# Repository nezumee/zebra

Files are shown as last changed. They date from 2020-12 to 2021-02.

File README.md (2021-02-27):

# Zebra
Zebra, adjustable column stagger keyboard

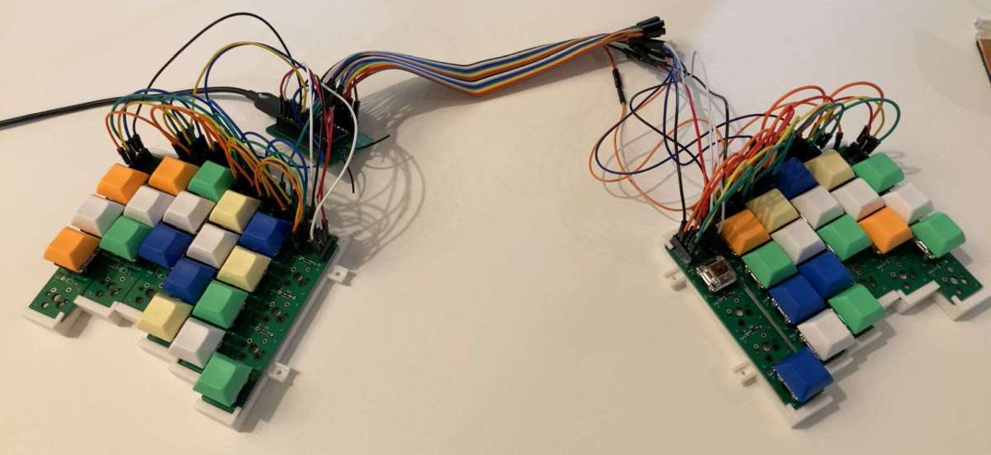
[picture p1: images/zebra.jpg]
zebra


# Overview
Zebra is a column staggered keyboard with independent PCBs for every column, allowing them to be put together in different positions or combinations without remaking any components or resoldering.

# Parts
For pictured configuration:
- Zebra head PCB x1 (see [KiCad](/PCB/Zebra) and [gerbers](/PCB/Gerber))
- Zebra stripe PCB x12. Up to 14 are supported, adjust other part counts accordingly if using more or less
- ProMicro, Elite C or equivalent x1
- ProMicro socket x1 (optional, I used https://www.digikey.com/en/products/detail/mill-max-manufacturing-corp/315-43-164-41-003000/1212143)
- 1N4148 diodes in through-hole package x48 (for example https://www.digikey.com/en/products/detail/1N4148TR/1N4148FSCT-ND/9356376?itemSeq=341430044)
- Kailh hotswap sockets x48 (optional)
- Single-line jumper wire headers x122 pins (remember every cut of header stripe means losing a pin. I bought 4x https://www.digikey.com/en/products/detail/chip-quik-inc/HDR100IMP40F-G-V-TH/5978200 and barely had any left. Get extras!)
- M/M jumper wires x65, at least 18 of them longer than 5 inches
- M/F jumper wire extender with at least 11 pins x1 (optional, to place the keyboard halves wider)
- Cherry MX switches and 1U keycaps of your choice x48
- Some way of holding the stripe PCBs in place: cardboard and sticky tape, or 3d printed enclosure, or anything else you come up with
- M2x5 screws and M2 nuts x20 (if using the 3d printed enclosure)
	
# Steps
## Solder the head PCB
1. Solder the ProMicro socket. Make sure to do it on the right side of the PCB depending on the way the pins on your ProMicro are oriented (Pin 1 is square on the PCB). My ProMicro has pins soldered so it's mounted upside down, with the MCU facing downwards
2. Solder the jumper headers on the same side
	
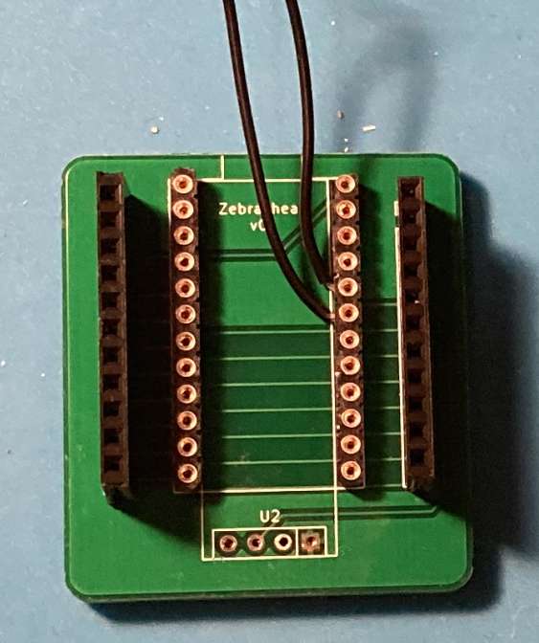
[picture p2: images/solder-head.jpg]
solder-head
	
	
	(ignore the wires in the picture)
	
## Solder the stripes
Solder the diodes, switch sockets and jumper headers
	
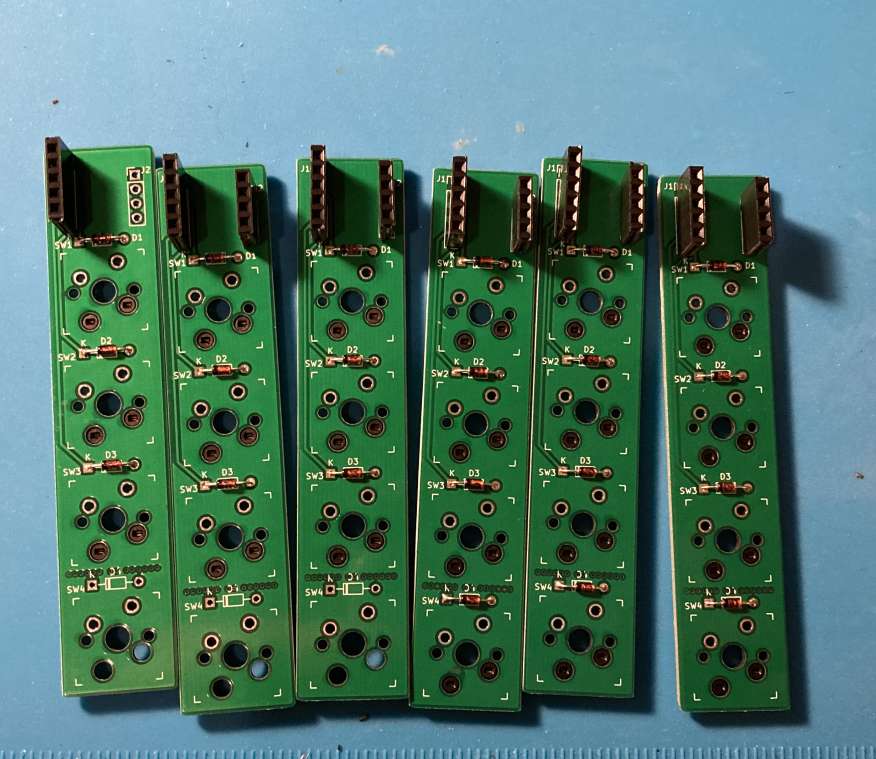
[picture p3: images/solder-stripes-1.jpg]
solder-stripes-1


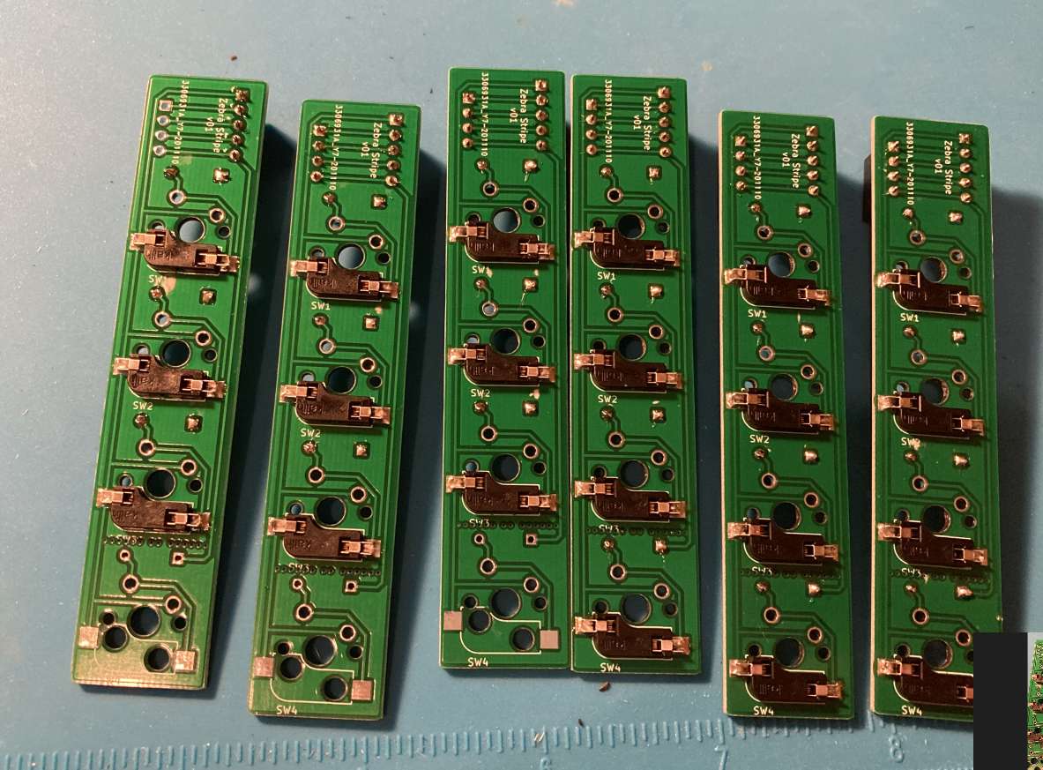
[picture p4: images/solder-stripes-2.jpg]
solder-stripes-1

	
You can skip soldering the diodes and sockets if you're not planning to use some switches (lower left).
	
## Connect the boards
Here's how the wires must be connected:
- Head

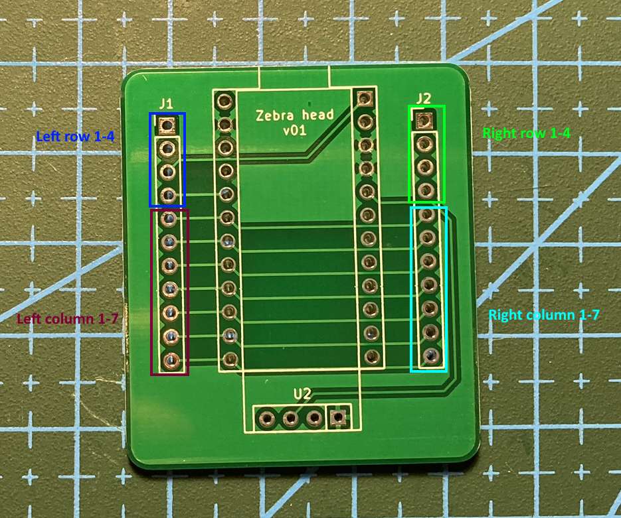
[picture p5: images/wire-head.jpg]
wire-head
	

	Note that the row wires are different between the left and right sides, don't connect them to each other!

- Stripes

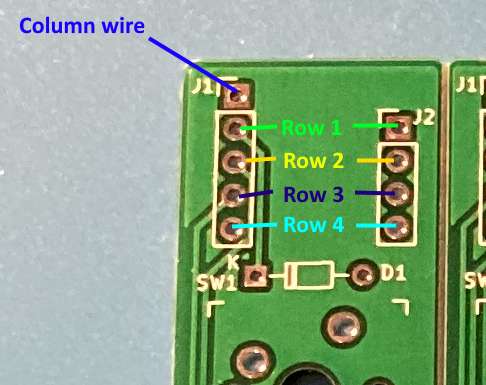
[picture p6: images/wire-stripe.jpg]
wire-stripe
	

- Overview of connections:

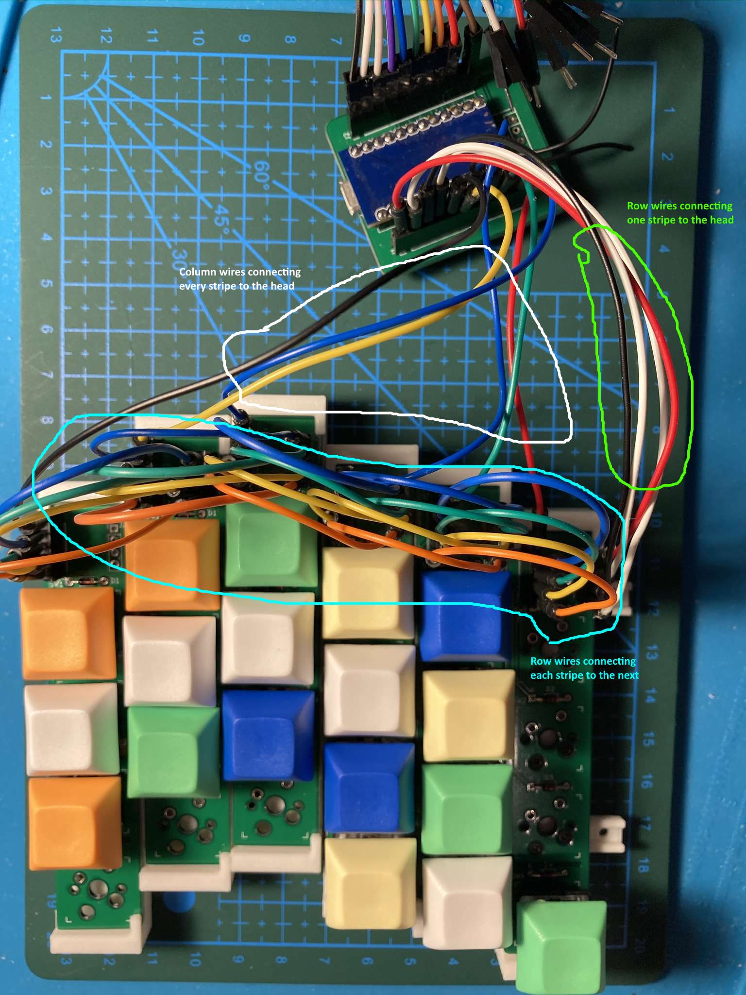
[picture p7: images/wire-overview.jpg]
wire-overview
	
	
- When connecting row wires between stripes, use the headers that are further apart so that the wires don't need to bend as much when the columns are arranged next to each other:

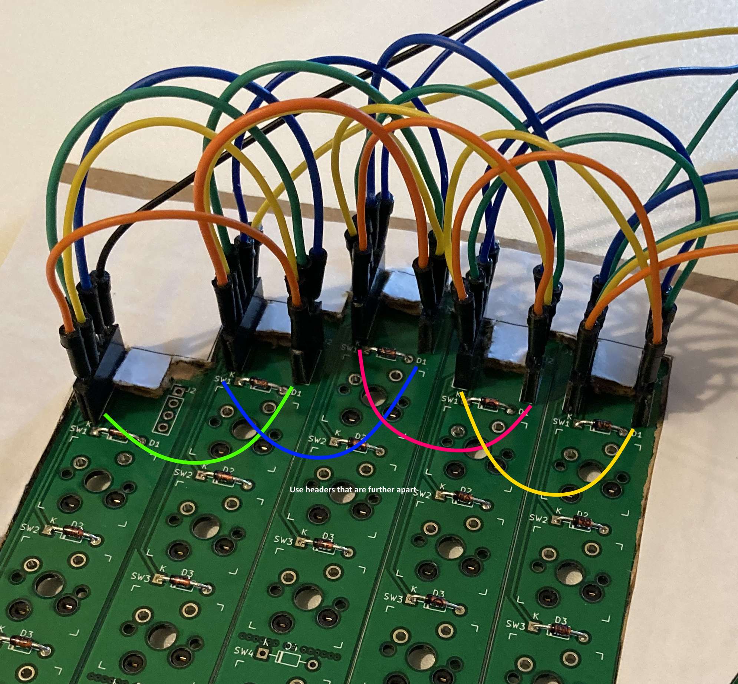
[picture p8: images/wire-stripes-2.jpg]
wire-stripes-2
	
	
## Arrange the boards
Now the difficult part - putting the stripes in place.

- Option 1: cut the shape out of cardboard that you want to place the stripes in, put some sticky tape at the back (glue side up), and stick the column boards to it:
	
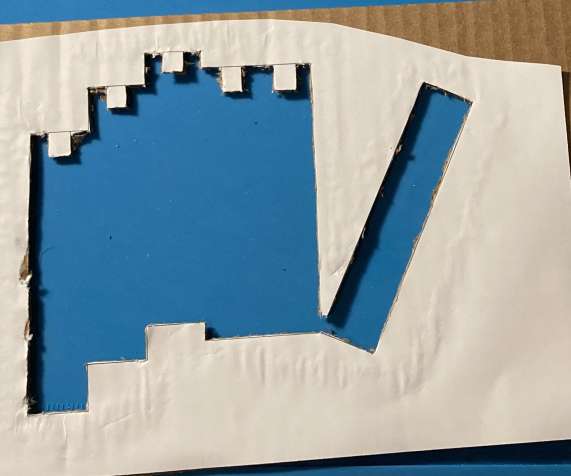
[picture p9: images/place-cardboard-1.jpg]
place-cardboard-1
	
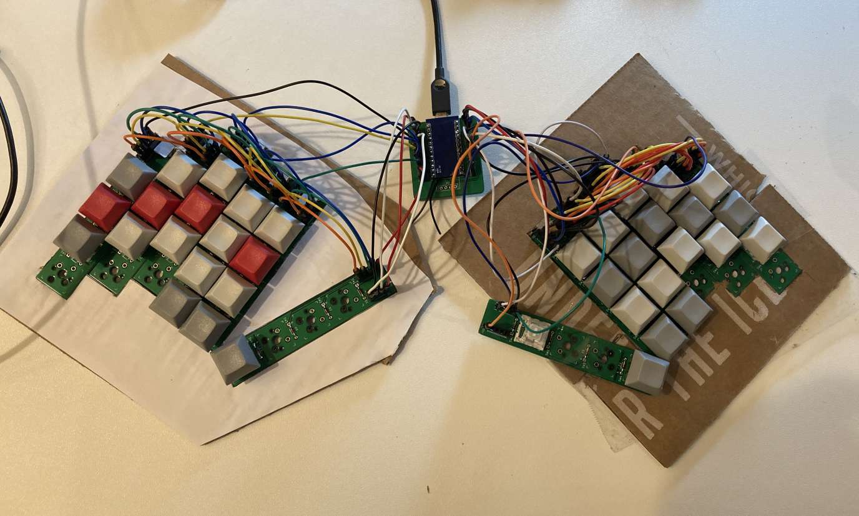
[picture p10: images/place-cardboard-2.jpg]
place-cardboard-2
	
	
	A template is available in [cardboard.svg](/Case/Cardboard.svg) file.
	
- Option 2: 3d print [stripe holders](/Case/3d-printed.stl), screw them together and insert the stripe PCBs:
	
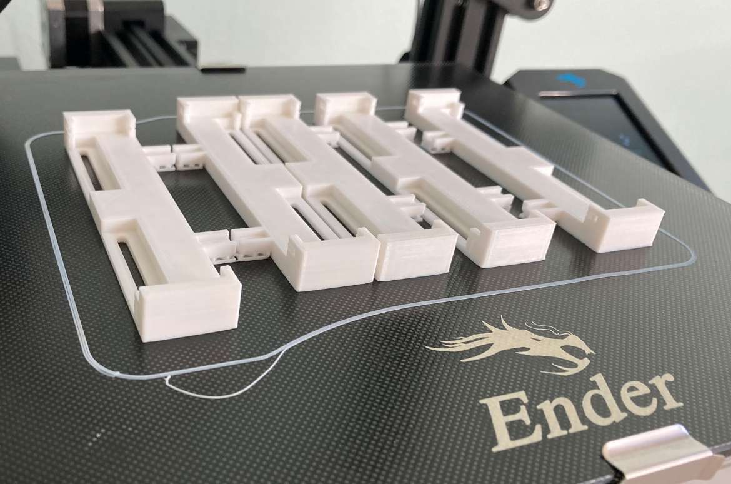
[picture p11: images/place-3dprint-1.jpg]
place-3dprint-1
	
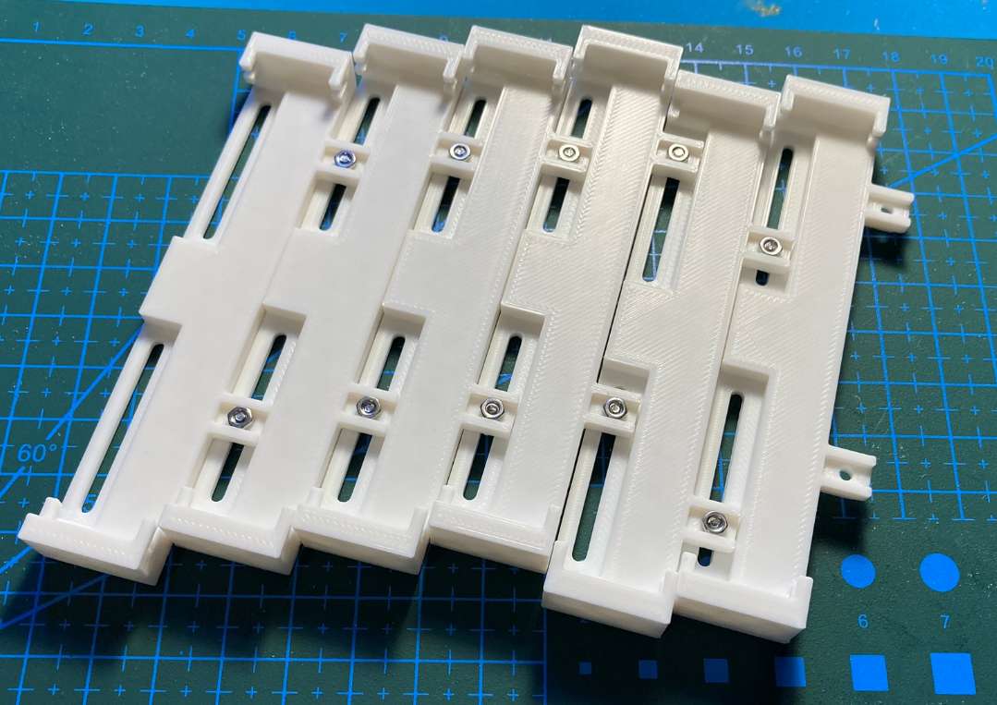
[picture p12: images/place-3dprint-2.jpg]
place-3dprint-2
	
	
	Note that a stripe allows changing stagger between 10mm in one direction and 20mm in another. Mirror half the stripes to flip which way gets more stagger on different sides of the keyboard.
	
	A basic ruler is built into the bottom of each stripe to measure the column stagger:
	
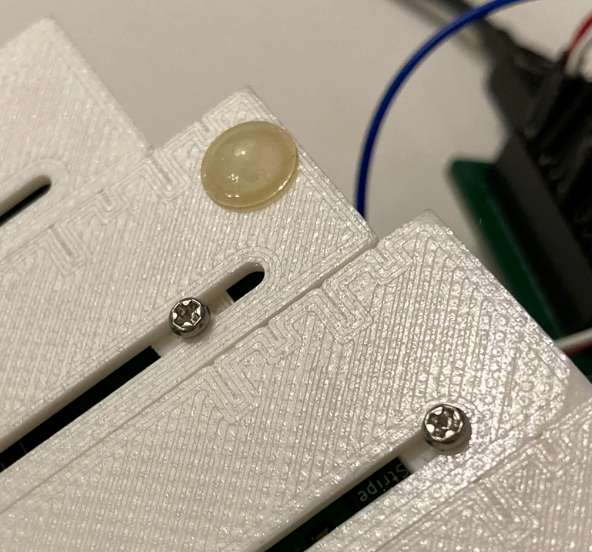
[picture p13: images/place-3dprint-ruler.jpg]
place-3dprint-ruler
	

# Firmware
Zebra is running QMK, see the source code under the QMK folder. Copy the [zebra](/QMK/zebra) folder under the keyboards folder in your QMK environment to compile. You can use JSON layout files made for Corne (LAYOUT_split_3x6_3) to build your layout in QMK configurator.

# Have fun
Try some popular or crazy configurations and see what you like!

Here's some examples:

- Let's split: no stagger

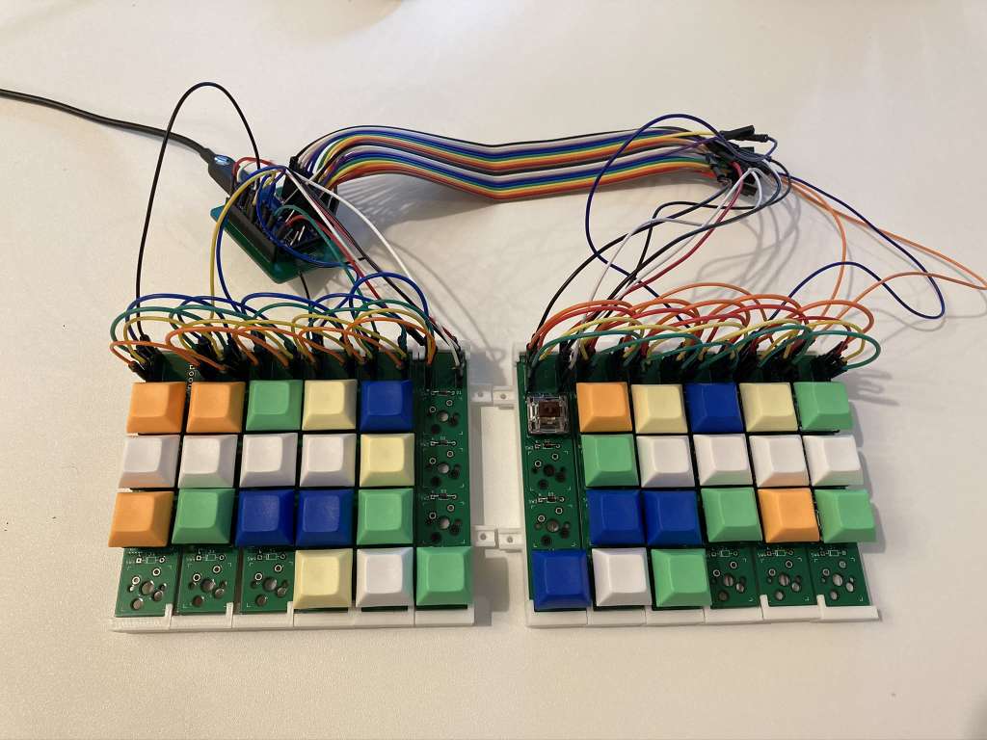
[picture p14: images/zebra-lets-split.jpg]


- Corne: index finger +2.4mm/middle +2.4mm/ring -2.4mm/pinky -4.8mm

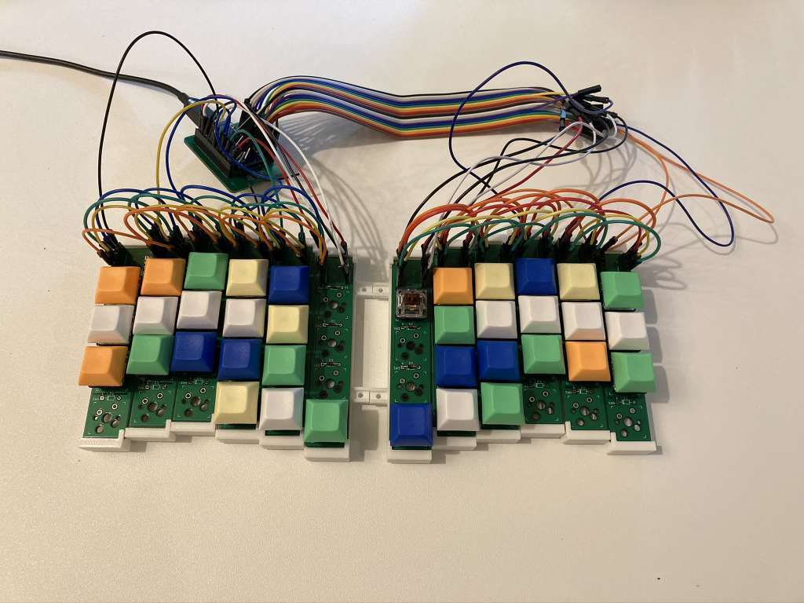
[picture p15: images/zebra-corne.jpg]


- Kyria: +2.5mm/+6.5mm/-6mm/-12mm

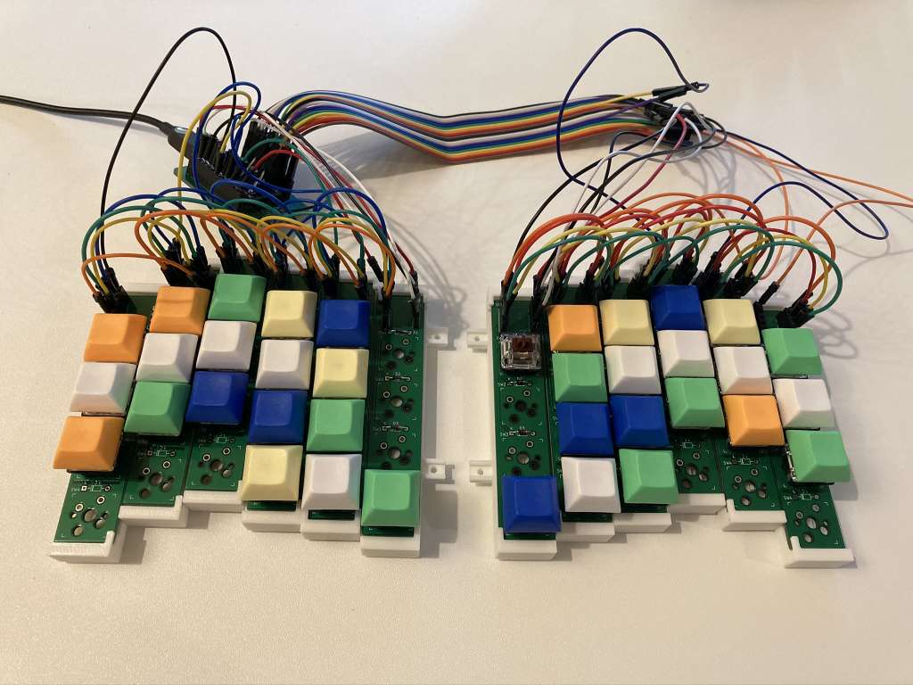
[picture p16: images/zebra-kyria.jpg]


- More aggressive stagger: +2.5mm/+10mm/-5mm/-14mm

zebra

- Tenting, encoders, true split and more in v2!

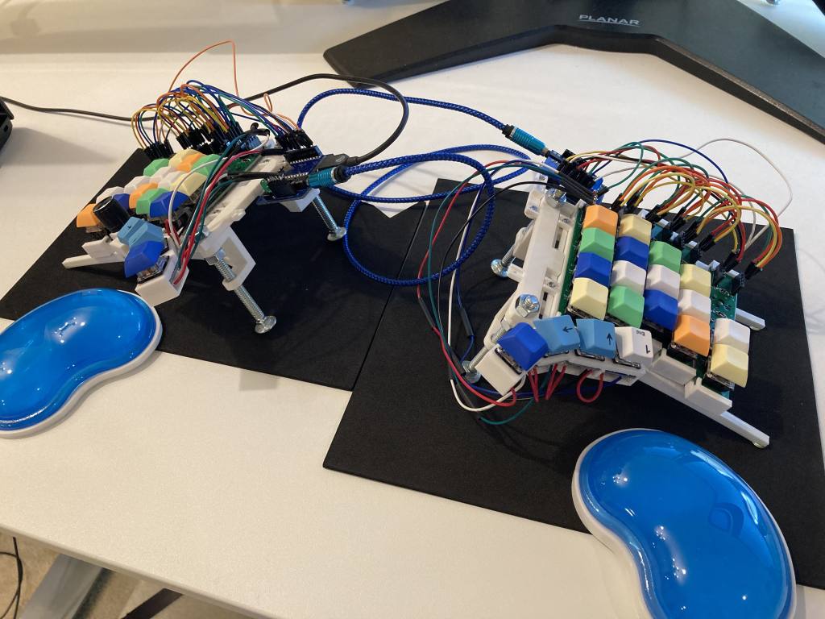
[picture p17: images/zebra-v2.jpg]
zebra-v2


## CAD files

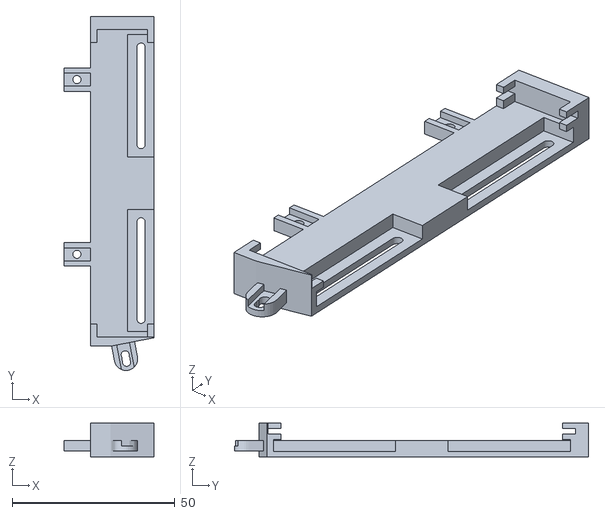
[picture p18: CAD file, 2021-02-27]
Case/Hoof Thumb connector.stl
27.7 x 108.8 x 10.4

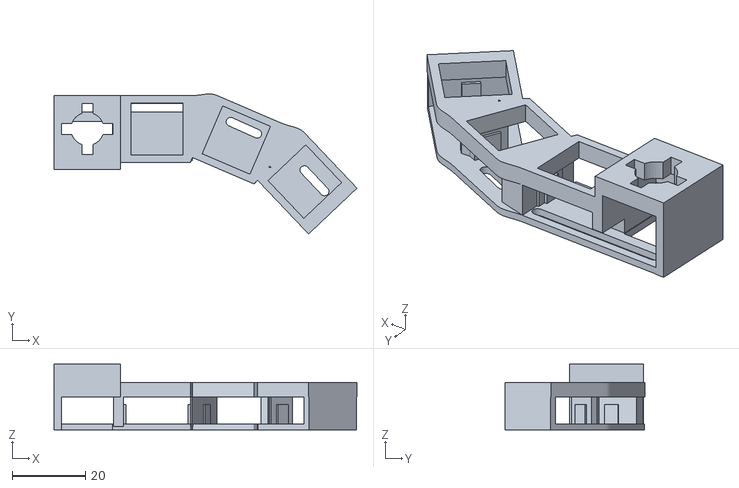
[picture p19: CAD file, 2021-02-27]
Case/Hoof Thumb stripe v2.stl
82.7 x 38.2 x 18.0

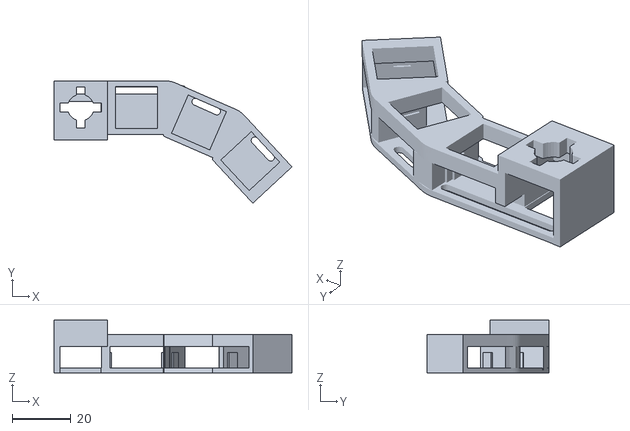
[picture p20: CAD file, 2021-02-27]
Case/Hoof Thumb stripe.stl
81.0 x 41.7 x 18.0

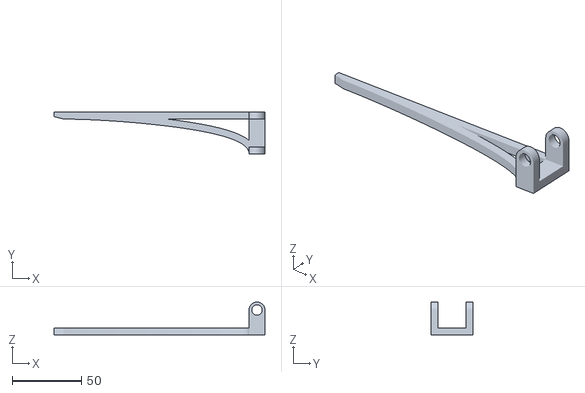
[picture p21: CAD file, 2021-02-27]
Case/Tenting support.stl
152.0 x 30.0 x 23.7

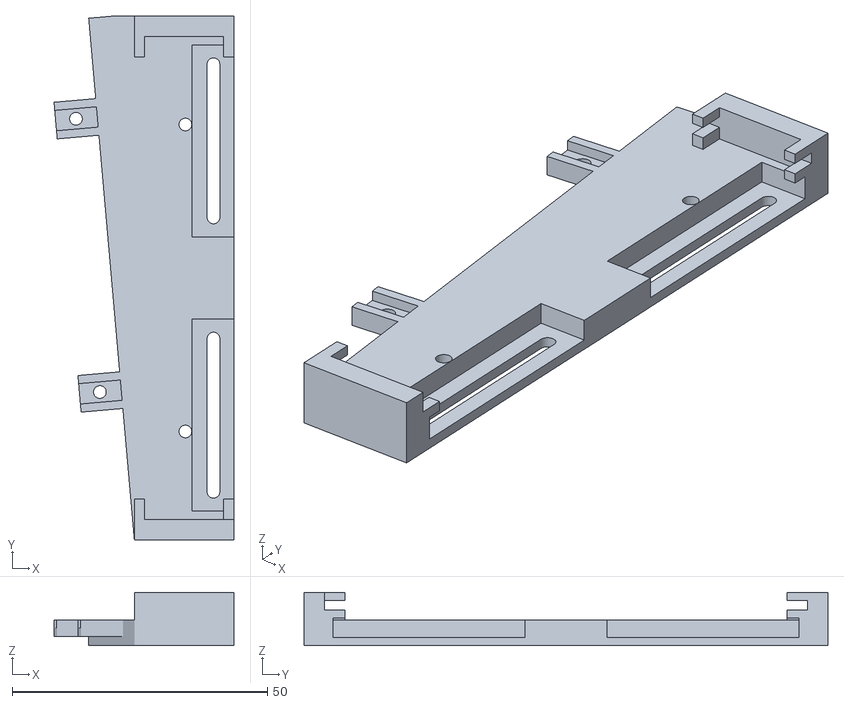
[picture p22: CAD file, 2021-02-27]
Case/Hoof Angled stripe.stl
35.2 x 102.5 x 10.4

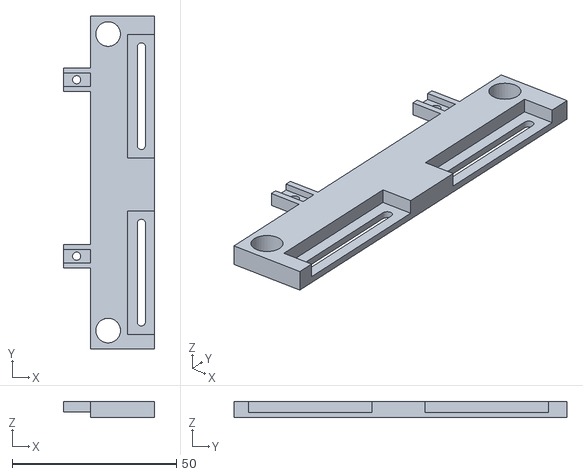
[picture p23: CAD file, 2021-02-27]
Case/Hoof Tenting.stl
27.7 x 101.3 x 5.00

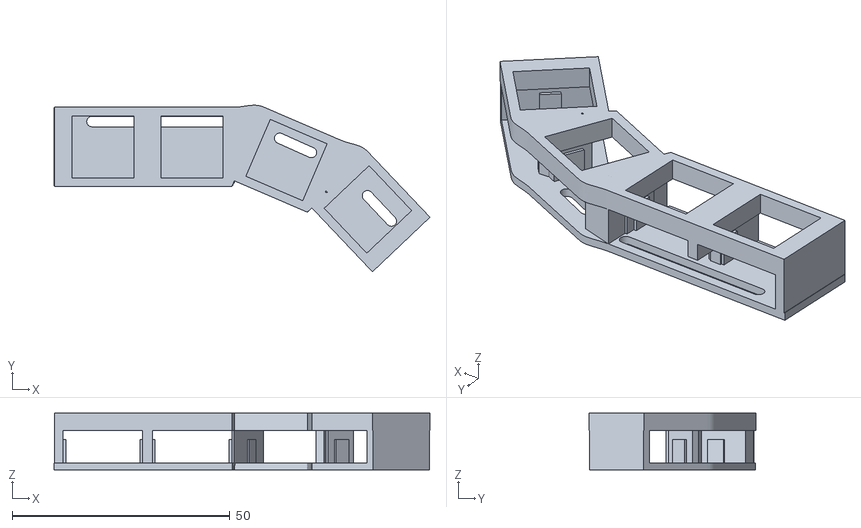
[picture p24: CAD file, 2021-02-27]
Case/Hoof Thumb Stripe no encoder.stl
86.3 x 38.2 x 13.0

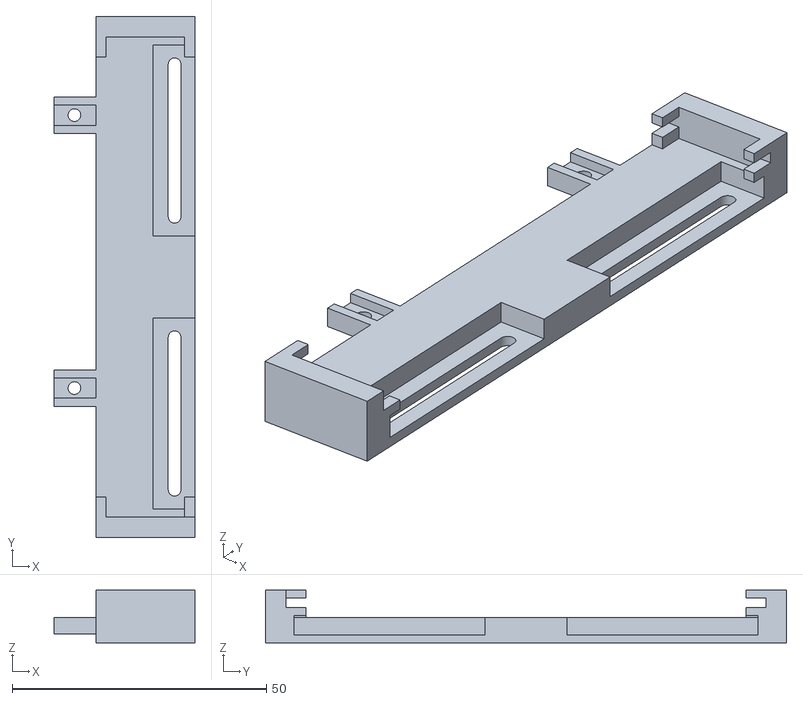
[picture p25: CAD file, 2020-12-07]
Case/3d-printed.stl
27.7 x 102.5 x 10.4

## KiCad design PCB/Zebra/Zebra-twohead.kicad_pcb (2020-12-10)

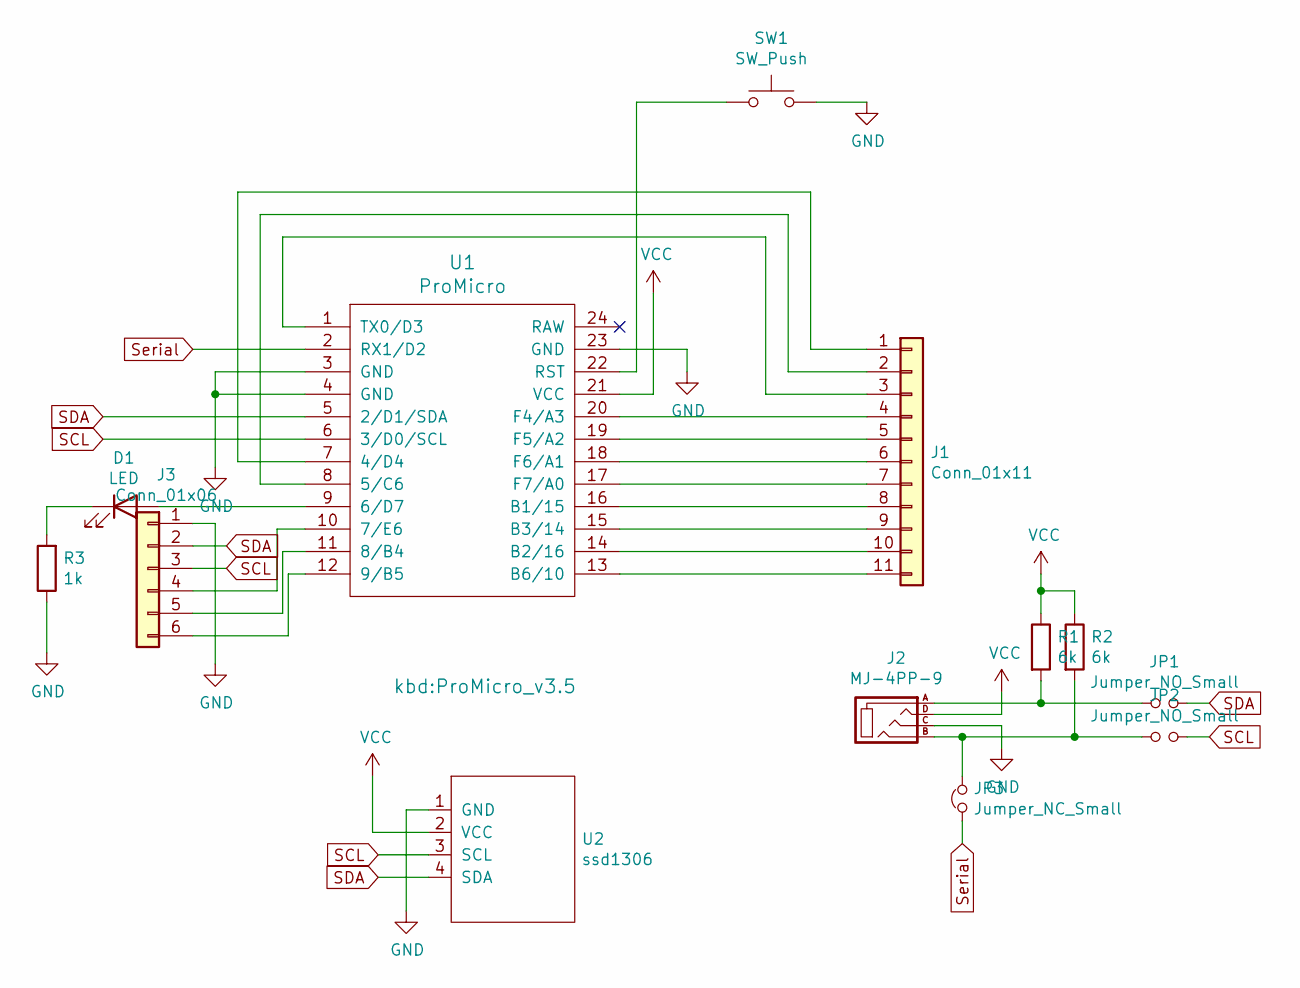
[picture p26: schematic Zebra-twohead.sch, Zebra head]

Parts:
D1: LED; LED_D3.0mm
J1: Conn_01x11; PinHeader_1x11_P2.54mm_Vertical
J2: MJ-4PP-9; MJ-4PP-9_1side
J3: Conn_01x06; PinHeader_1x06_P2.54mm_Vertical
JP1, JP2: Jumper_NO_Small; SolderJumper-2_P1.3mm_Open_Pad1.0x1.5mm
JP3: Jumper_NC_Small; SolderJumper-2_P1.3mm_Bridged_Pad1.0x1.5mm
R1, R2: 6k; R_1206_3216Metric_Pad1.30x1.75mm_HandSolder
R3: 1k; R_1206_3216Metric_Pad1.30x1.75mm_HandSolder
SW1: SW_Push; ResetSW_1side
U1: ProMicro; ProMicro_v3.5
U2: ssd1306; SSD1306

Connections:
GND: J2.C, J3.1, R3.1, SW1.2, U1.3 (GND), U1.4 (GND), U1.23 (GND), U2.1 (GND)
unnamed: D1.1 (K), R3.2
unnamed: D1.2 (A), U1.9 (6/D7)
unnamed: J1.1, U1.7 (4/D4)
unnamed: J1.2, U1.8 (5/C6)
unnamed: J1.3, U1.1 (TX0/D3)
unnamed: J1.4, U1.20 (F4/A3)
unnamed: J1.5, U1.19 (F5/A2)
unnamed: J1.6, U1.18 (F6/A1)
unnamed: J1.7, U1.17 (F7/A0)
unnamed: J1.8, U1.16 (B1/15)
unnamed: J1.9, U1.15 (B3/14)
unnamed: J1.10, U1.14 (B2/16)
unnamed: J1.11, U1.13 (B6/10)
unnamed: J2.A, JP1.1, R1.2
unnamed: J2.B, JP2.1, JP3.2, R2.2
unnamed: J3.4, U1.10 (7/E6)
unnamed: J3.5, U1.11 (8/B4)
unnamed: J3.6, U1.12 (9/B5)
unnamed: SW1.1, U1.22 (RST)
SCL: J3.3, JP2.2, U1.6 (3/D0/SCL), U2.3 (SCL)
SDA: J3.2, JP1.2, U1.5 (2/D1/SDA), U2.4 (SDA)
Serial: JP3.1, U1.2 (RX1/D2)
VCC: J2.D, R1.1, R2.1, U1.21 (VCC), U2.2 (VCC)

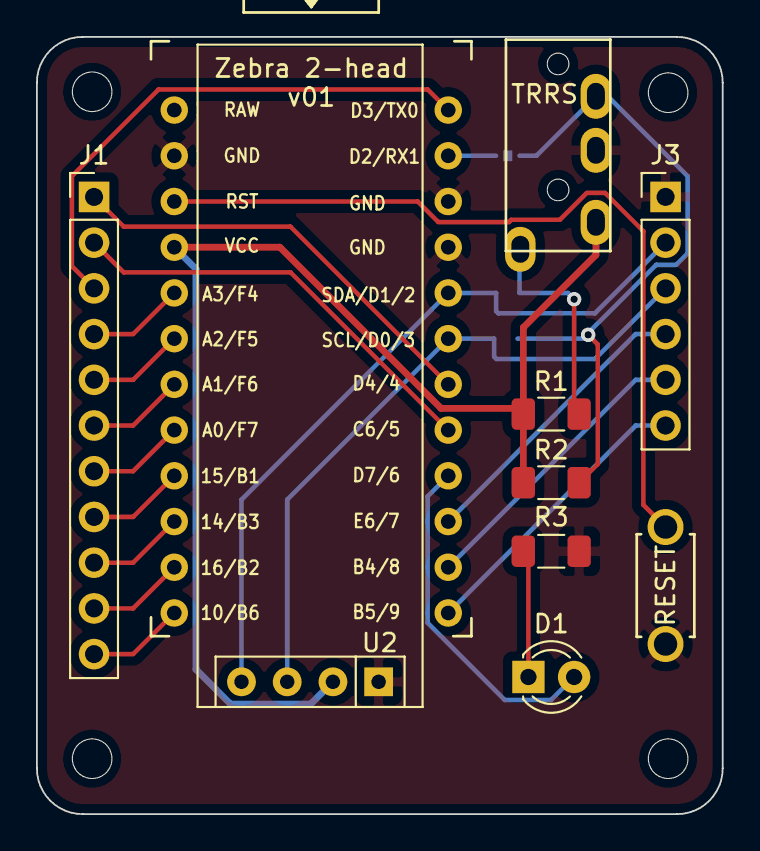
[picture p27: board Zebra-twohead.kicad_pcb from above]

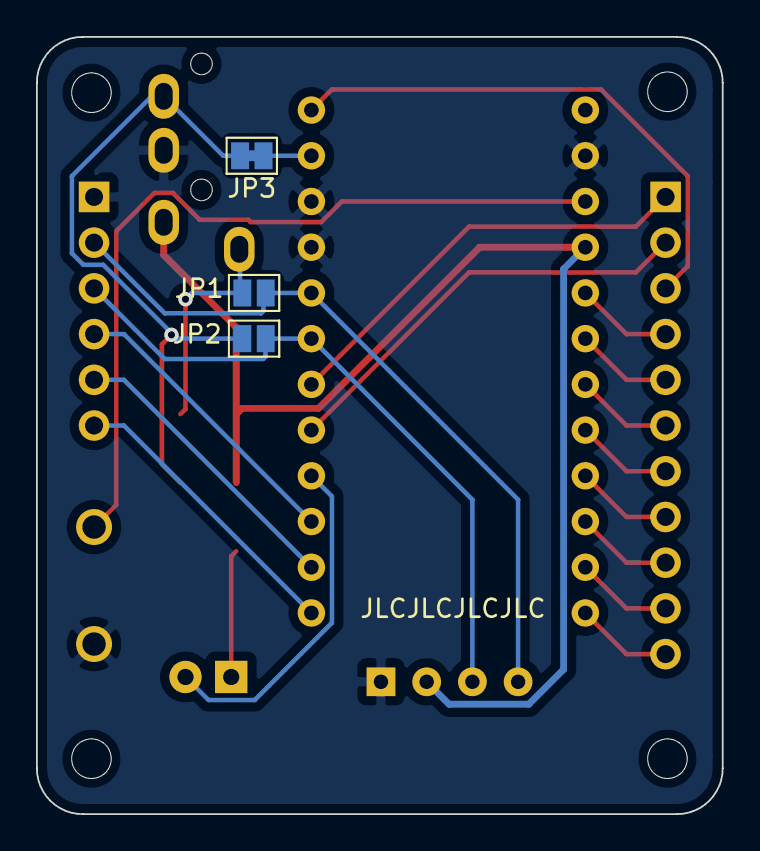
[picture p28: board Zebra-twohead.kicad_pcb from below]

Board: 2 copper layers, 38.1 x 43.2 mm, 13 parts (3 on the bottom side), 24 nets.

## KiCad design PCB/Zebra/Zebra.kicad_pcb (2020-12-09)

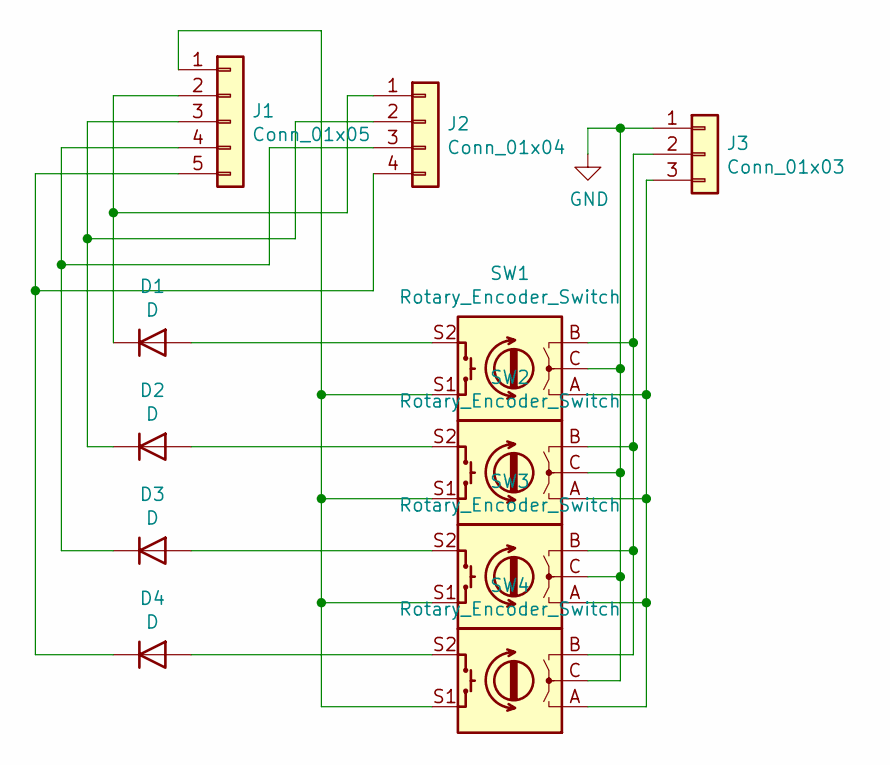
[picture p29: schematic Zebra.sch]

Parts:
D1, D2, D3, D4: D; D_DO-34_SOD68_P7.62mm_Horizontal
J1: Conn_01x05; PinHeader_1x05_P2.54mm_Vertical
J2: Conn_01x04; PinHeader_1x04_P2.54mm_Vertical
J3: Conn_01x03; PinHeader_1x03_P2.54mm_Vertical
SW1, SW2, SW3, SW4: Rotary_Encoder_Switch; CherryMX_Hotswap_Encoder

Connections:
GND: J3.1, SW1.C, SW2.C, SW3.C, SW4.C
unnamed: D1.1 (K), J1.2, J2.1
unnamed: D1.2 (A), SW1.S2
unnamed: D2.1 (K), J1.3, J2.2
unnamed: D2.2 (A), SW2.S2
unnamed: D3.1 (K), J1.4, J2.3
unnamed: D3.2 (A), SW3.S2
unnamed: D4.1 (K), J1.5, J2.4
unnamed: D4.2 (A), SW4.S2
unnamed: J1.1, SW1.S1, SW2.S1, SW3.S1, SW4.S1
unnamed: J3.2, SW1.B, SW2.B, SW3.B, SW4.B
unnamed: J3.3, SW1.A, SW2.A, SW3.A, SW4.A

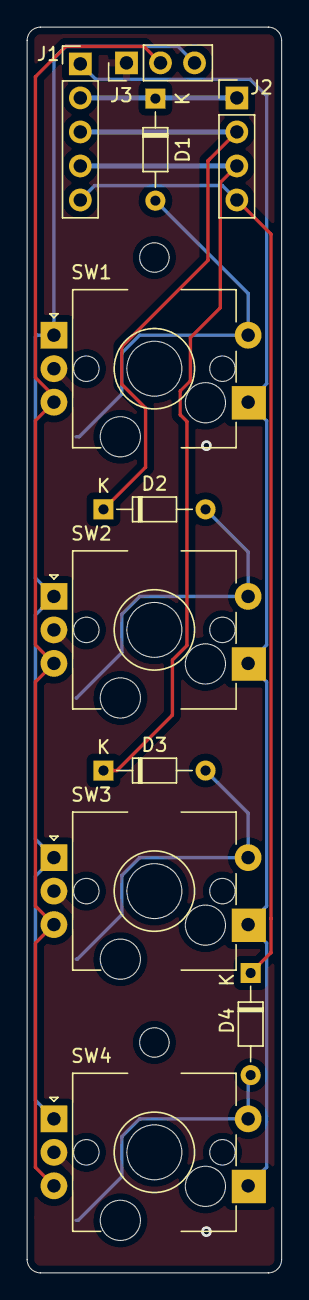
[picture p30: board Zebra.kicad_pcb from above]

Board: 2 copper layers, 19.0 x 93.0 mm, 12 parts (0 on the bottom side), 12 nets.

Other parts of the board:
 : MountingHole_2.2mm_M2

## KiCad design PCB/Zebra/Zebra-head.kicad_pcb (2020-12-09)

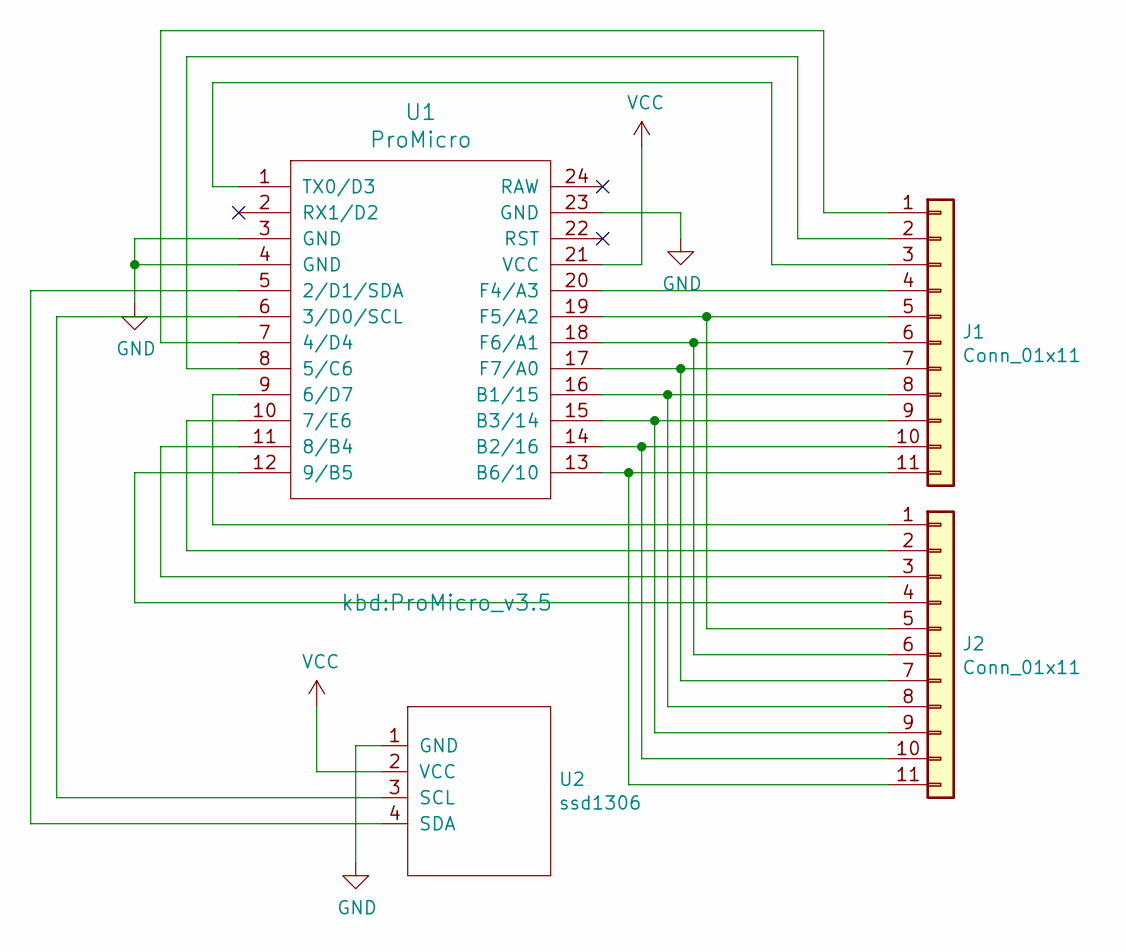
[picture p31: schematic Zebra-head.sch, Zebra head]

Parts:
J1, J2: Conn_01x11; PinHeader_1x11_P2.54mm_Vertical
U1: ProMicro; ProMicro_v3.5
U2: ssd1306; SSD1306

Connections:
GND: U1.3 (GND), U1.4 (GND), U1.23 (GND), U2.1 (GND)
unnamed: J1.1, U1.7 (4/D4)
unnamed: J1.2, U1.8 (5/C6)
unnamed: J1.3, U1.1 (TX0/D3)
unnamed: J1.4, U1.20 (F4/A3)
unnamed: J1.5, J2.5, U1.19 (F5/A2)
unnamed: J1.6, J2.6, U1.18 (F6/A1)
unnamed: J1.7, J2.7, U1.17 (F7/A0)
unnamed: J1.8, J2.8, U1.16 (B1/15)
unnamed: J1.9, J2.9, U1.15 (B3/14)
unnamed: J1.10, J2.10, U1.14 (B2/16)
unnamed: J1.11, J2.11, U1.13 (B6/10)
unnamed: J2.1, U1.9 (6/D7)
unnamed: J2.2, U1.10 (7/E6)
unnamed: J2.3, U1.11 (8/B4)
unnamed: J2.4, U1.12 (9/B5)
unnamed: U1.5 (2/D1/SDA), U2.4 (SDA)
unnamed: U1.6 (3/D0/SCL), U2.3 (SCL)
VCC: U1.21 (VCC), U2.2 (VCC)

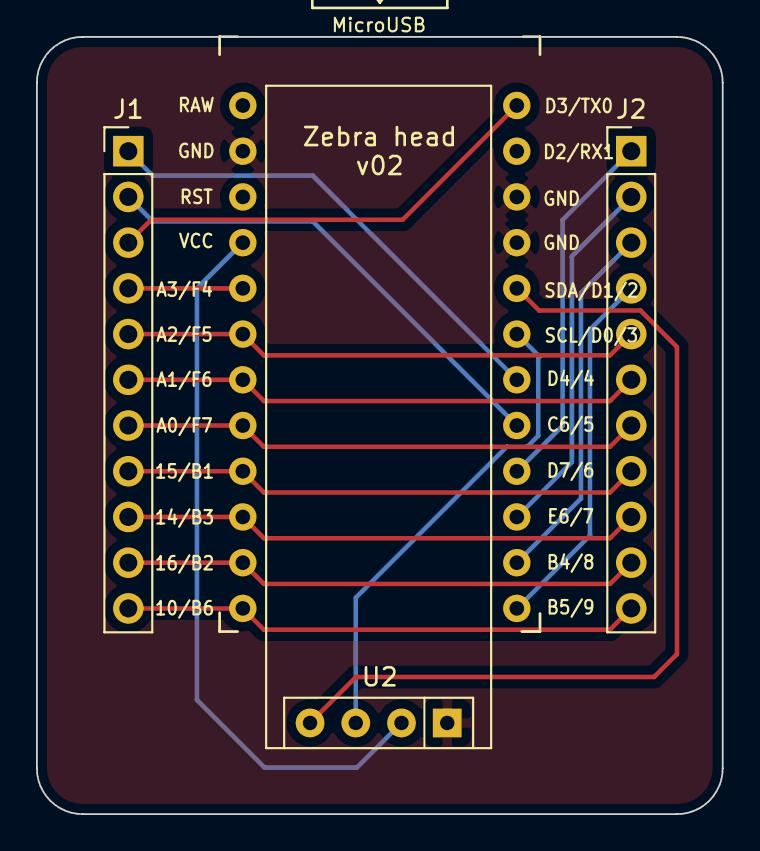
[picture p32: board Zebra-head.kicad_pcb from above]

Board: 2 copper layers, 38.1 x 43.2 mm, 4 parts (0 on the bottom side), 19 nets.

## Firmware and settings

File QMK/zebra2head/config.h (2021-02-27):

#ifndef CONFIG_H
#define CONFIG_H

#include "config_common.h"

/* USB Device descriptor parameter */
#define VENDOR_ID       0xFEED
#define PRODUCT_ID      0x6062
#define DEVICE_VER      0x0001
#define MANUFACTURER    nezumee
#define PRODUCT         zebra2head
#define DESCRIPTION     Zebra Two Head

/* key matrix size */
#define MATRIX_ROWS 8
#define MATRIX_COLS 7

/* key matrix pins */
#define MATRIX_ROW_PINS { D4, C6, D3, F4 }
#define MATRIX_COL_PINS { F5, F6, F7, B1, B3, B2, B6 }
#define UNUSED_PINS

/* COL2ROW or ROW2COL */
#define DIODE_DIRECTION COL2ROW

/* number of backlight levels */
#define BACKLIGHT_PIN D7
#ifdef BACKLIGHT_PIN
#define BACKLIGHT_LEVELS 3
#endif

/* Set 0 if debouncing isn't needed */
#define DEBOUNCING_DELAY 20
#define DEBOUNCE 20

#define ENCODERS_PAD_A { B4 }
#define ENCODERS_PAD_B { B5 }

/* Mechanical locking support. Use KC_LCAP, KC_LNUM or KC_LSCR instead in keymap */
#define LOCKING_SUPPORT_ENABLE

/* Locking resynchronize hack */
#define LOCKING_RESYNC_ENABLE

#define SOFT_SERIAL_PIN D2

/* key combination for command */
#define IS_COMMAND() ( \
    keyboard_report->mods == (MOD_BIT(KC_LSHIFT) | MOD_BIT(KC_RSHIFT)) \
)

/* prevent stuck modifiers */
#define PREVENT_STUCK_MODIFIERS


#ifdef RGB_DI_PIN
#define RGBLIGHT_ANIMATIONS
#define RGBLED_NUM 0
#define RGBLIGHT_HUE_STEP 8
#define RGBLIGHT_SAT_STEP 8
#define RGBLIGHT_VAL_STEP 8
#endif

#endif

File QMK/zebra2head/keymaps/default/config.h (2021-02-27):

// generated from users/manna-harbour_miryoku/miryoku.org  -*- buffer-read-only: t -*-

#pragma once

// default but important
#define TAPPING_TERM 170
#define TAPPING_TERM_PER_KEY

// Prevent normal rollover on alphas from accidentally triggering mods.
#define IGNORE_MOD_TAP_INTERRUPT

// Enable rapid switch from tap to hold, disables double tap hold auto-repeat.
// #define TAPPING_FORCE_HOLD

// Recommended for heavy chording.
#define QMK_KEYS_PER_SCAN 4

// Mouse key speed and acceleration.
#undef MOUSEKEY_DELAY
#define MOUSEKEY_DELAY          0
#undef MOUSEKEY_INTERVAL
#define MOUSEKEY_INTERVAL       16
#undef MOUSEKEY_WHEEL_DELAY
#define MOUSEKEY_WHEEL_DELAY    0
#undef MOUSEKEY_MAX_SPEED
#define MOUSEKEY_MAX_SPEED      6
#undef MOUSEKEY_TIME_TO_MAX
#define MOUSEKEY_TIME_TO_MAX    64

#define COMBO_COUNT 21

#define TAPPING_FORCE_HOLD_PER_KEY

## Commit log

2020-12-06 Add keyboard files
    [Zebra-head.kicad_pcb, Zebra-head.sch, Zebra.kicad_pcb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]
2020-12-07 Add case files and examples
    [3d-printed.stl]
2020-12-09 Switch to foostan's footprint library, MIT license
    [Zebra-head.kicad_pcb, Zebra-head.sch, Zebra.kicad_pcb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]
2020-12-09 Add TRRS jack
    With serial and optional I2C
    [Zebra-head.kicad_pcb, Zebra-head.sch]
2020-12-09 Revert "Add TRRS jack"
    This reverts commit 0ecc4aa986bd018de9fb38d5a9cbe8efcda9557b.
    [Zebra-head.kicad_pcb, Zebra-head.sch]
2020-12-09 Add Zebra 2-head separately
    [Zebra-twohead.kicad_pcb, Zebra-twohead.sch]
2020-12-09 Add encoders
    [Zebra.kicad_pcb, Zebra.sch]
2020-12-09 Rename switches, renumber
    [Zebra.kicad_pcb, Zebra.sch]
2020-12-09 Add mounting holes to the stripe
    [Zebra.kicad_pcb]
2020-12-10 Add extra connector, LED, clean up
    [Zebra-twohead.kicad_pcb, Zebra-twohead.sch]
2020-12-10 Make gerbers
2021-02-27 Add tenting, angled, thumb stripe models
    [Hoof Angled stripe.stl, Hoof Tenting.stl, Hoof Thumb Stripe no encoder.stl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]
